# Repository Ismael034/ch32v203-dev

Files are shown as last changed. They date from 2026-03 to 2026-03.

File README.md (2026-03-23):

# ch32v203-devboard

Just another CH32V203 development board.

With dual USB, exposed GPIOs, and a SWD header, this board is meant to make it easy to create projects for the CH32V203 microcontroller.

## Screenshots

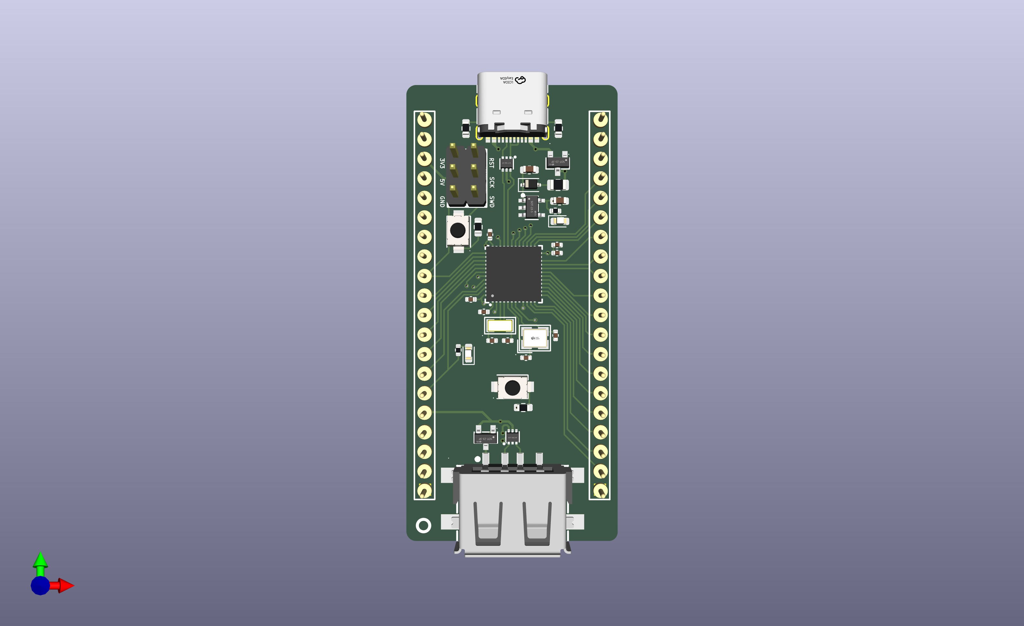
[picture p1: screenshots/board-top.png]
Board top

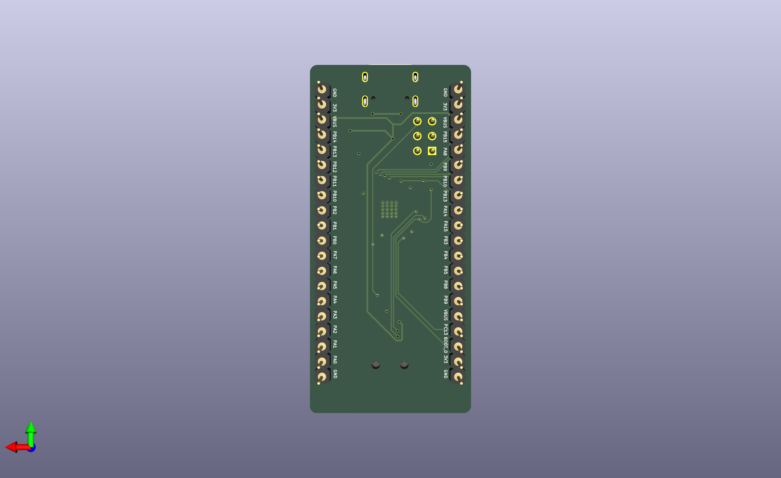
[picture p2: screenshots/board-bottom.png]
Board bottom

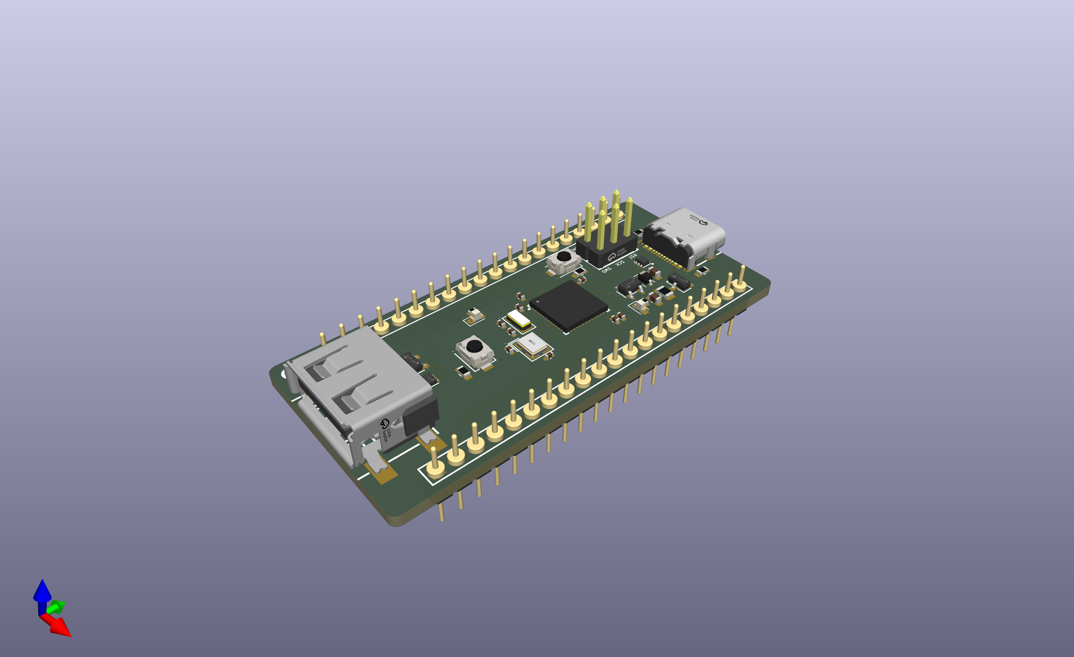
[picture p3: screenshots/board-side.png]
Board side


## BOM

| Qty | Designators | Description | Footprint |
| --- | --- | --- | --- |
| 2 | C1, C2 | 10 uF capacitors | `Capacitor_SMD:C_0603_1608Metric` |
| 4 | C3, C4, C9, C10 | 15 pF capacitors | `Capacitor_SMD:C_0402_1005Metric` |
| 3 | C5, C6, C7 | 100 nF capacitors | `Capacitor_SMD:C_0402_1005Metric` |
| 1 | C8 | 4.7 uF capacitor | `Capacitor_SMD:C_0402_1005Metric` |
| 1 | C11 | 10 uF capacitor | `Capacitor_SMD:C_0402_1005Metric` |
| 2 | D1, D2 | USBLC6-2P6 ESD protection | `ch32v203_dev:SOT-666-6_L1.6-W1.2-P0.50-LS1.6-BL` |
| 1 | F1 | JK-SMD0805-020-30V fuse | `Fuse:Fuse_0805_2012Metric` |
| 2 | H1, H2 | 1x20 2.54 mm pin headers | `ch32v203_dev:HDR-TH_20P-P2.54-V-M_4` |
| 1 | LED1 | User LED, XL-1608UGC-04 | `LED_SMD:LED_0603_1608Metric` |
| 1 | LDO1 | ME6211C33M5G-N 3.3 V LDO | `ch32v203_dev:SOT-23-5_L3.0-W1.7-P0.95-LS2.8-BL` |
| 1 | PWR1 | Power LED, NCD0603R1 | `LED_SMD:LED_0603_1608Metric` |
| 2 | R2, R3 | 10 kOhm resistors | `Resistor_SMD:R_0603_1608Metric` |
| 2 | R4, R5 | 1 kOhm resistors | `Resistor_SMD:R_0402_1005Metric` |
| 2 | R1, R6 | 5.1 kOhm resistors | `Resistor_SMD:R_0603_1608Metric` |
| 2 | RESET1, RESET2 | SMD tactile switches | `ch32v203_dev:SW-SMD_L3.9-W3.0-P4.45` |
| 1 | U1 | CH32V203C8U6 MCU | `ch32v203_dev:TQFN-48_L7.0-W7.0-P0.50-BL-EP5.5` |
| 1 | U2 | 2x3 2.54 mm SWD header | `ch32v203_dev:HDR-TH_6P-P2.54-V-M-R3-C2-S2.54_2` |
| 1 | U3 | 32.768 kHz crystal | `ch32v203_dev:CRYSTAL-SMD_L3.2-W1.5-1` |
| 1 | U4 | USB-C receptacle KH-TYPE-C-16P | `ch32v203_dev:USB-C-SMD_KH-TYPE-C-16P` |
| 1 | U5 | SD101CWS diode | `Diode_SMD:D_SOD-323` |
| 2 | U6, U7 | DMG2305UX-7 MOSFET | `ch32v203_dev:SOT-23-3_L2.9-W1.3-P1.90-LS2.4-BR` |
| 1 | USB2 | USB-A receptacle 10.0 QTJ6.3 | `ch32v203_dev:USB-A-SMD_10.0-QTJ6.3` |
| 1 | X1 | 8 MHz crystal | `ch32v203_dev:CRYSTAL-SMD_4P-L3.2-W2.5-BL` |

## Some notes

- You can either program the board using the USB-C port (by pressing the BOOT button while plugging in the USB cable) or using the SWD header.
- The board has a built-in LED mapped to PB9.
- The board dimensions are 27.9mm (takes 10 breadboard pins) x 59.9mm

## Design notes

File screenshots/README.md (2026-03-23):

# Screenshots

Drop rendered images or board photos here.

Suggested files:

- `board-top.png`
- `board-bottom.png`
- `schematic-overview.png`
- `3d-view.png`

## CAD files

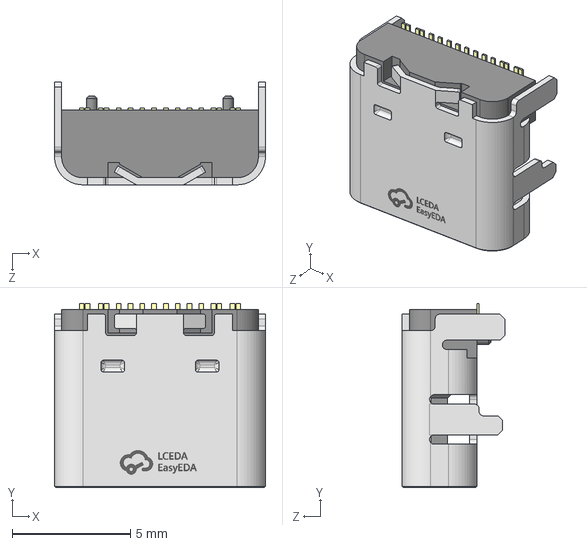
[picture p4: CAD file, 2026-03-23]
ch32v203_dev_fp/ch32v203_dev_model/USB-C-SMD_KH-TYPE-C-16P.step
8.94 x 7.81 x 4.35 mm

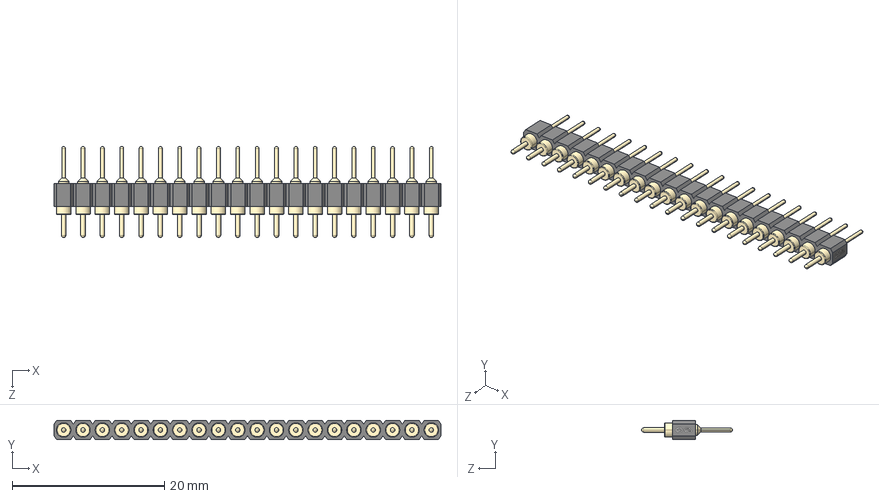
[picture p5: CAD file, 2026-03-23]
ch32v203_dev_fp/ch32v203_dev_model/HDR-TH_20P-P2.54-V-M_4.step
50.8 x 2.54 x 12.0 mm

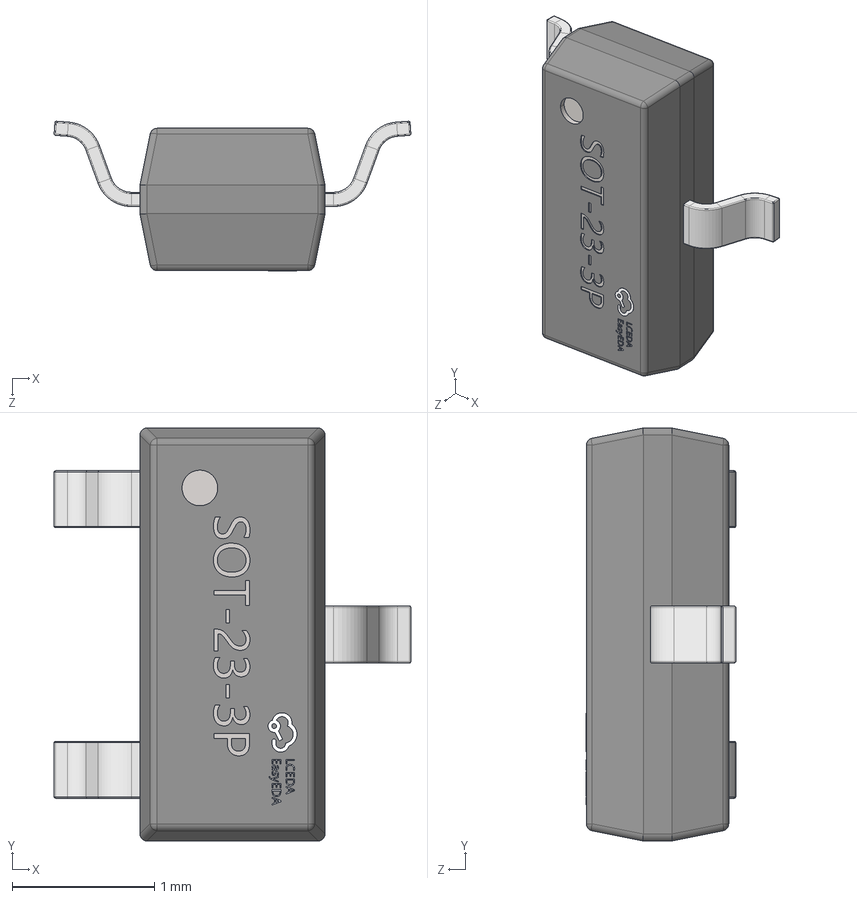
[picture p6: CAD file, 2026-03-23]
ch32v203_dev_fp/ch32v203_dev_model/SOT-23-3_L2.9-W1.3-P1.90-LS2.4-BR.step
2.51 x 2.90 x 1.05 mm

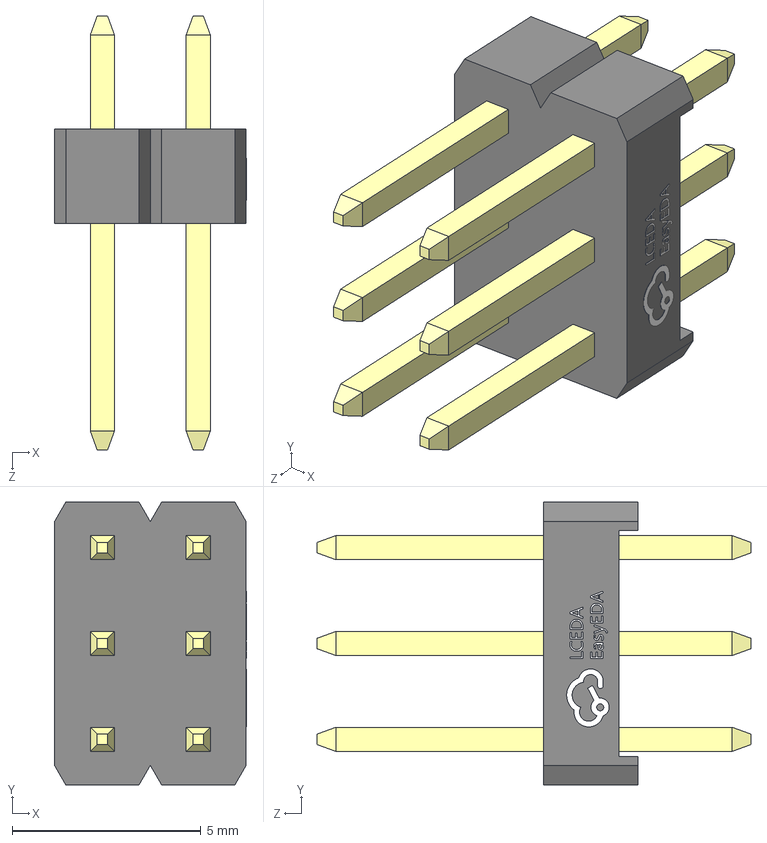
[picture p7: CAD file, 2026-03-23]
ch32v203_dev_fp/ch32v203_dev_model/HDR-TH_6P-P2.54-V-M-R3-C2-S2.54_2.step
5.09 x 7.50 x 11.5 mm

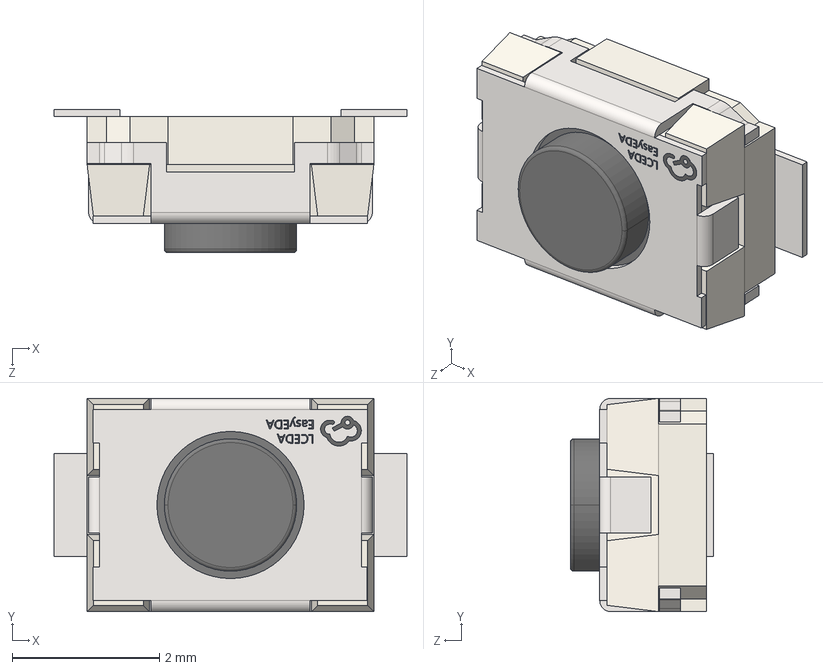
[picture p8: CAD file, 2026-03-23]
ch32v203_dev_fp/ch32v203_dev_model/SW-SMD_L3.9-W3.0-P4.45.step
4.80 x 2.90 x 1.95 mm

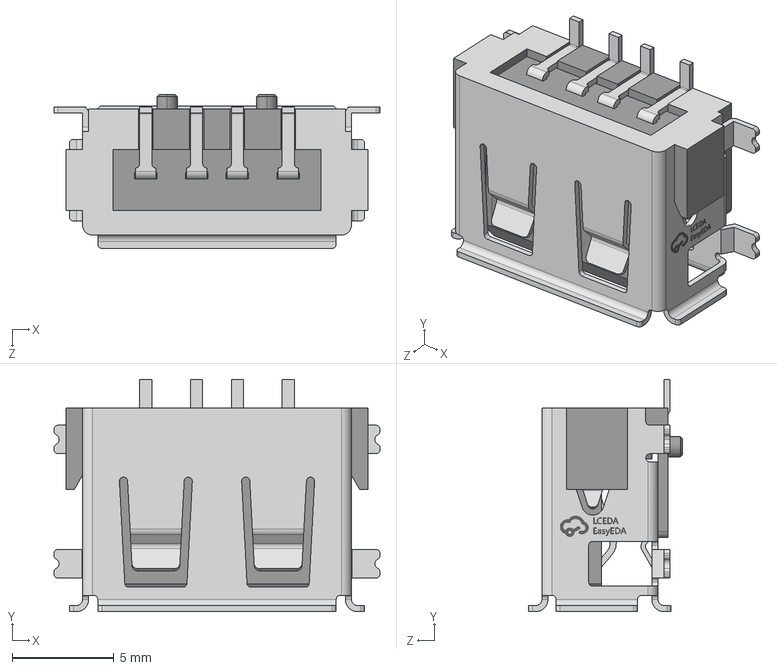
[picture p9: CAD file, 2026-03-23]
ch32v203_dev_fp/ch32v203_dev_model/USB-A-SMD_10.0-QTJ6.3.step
16.0 x 11.4 x 7.55 mm

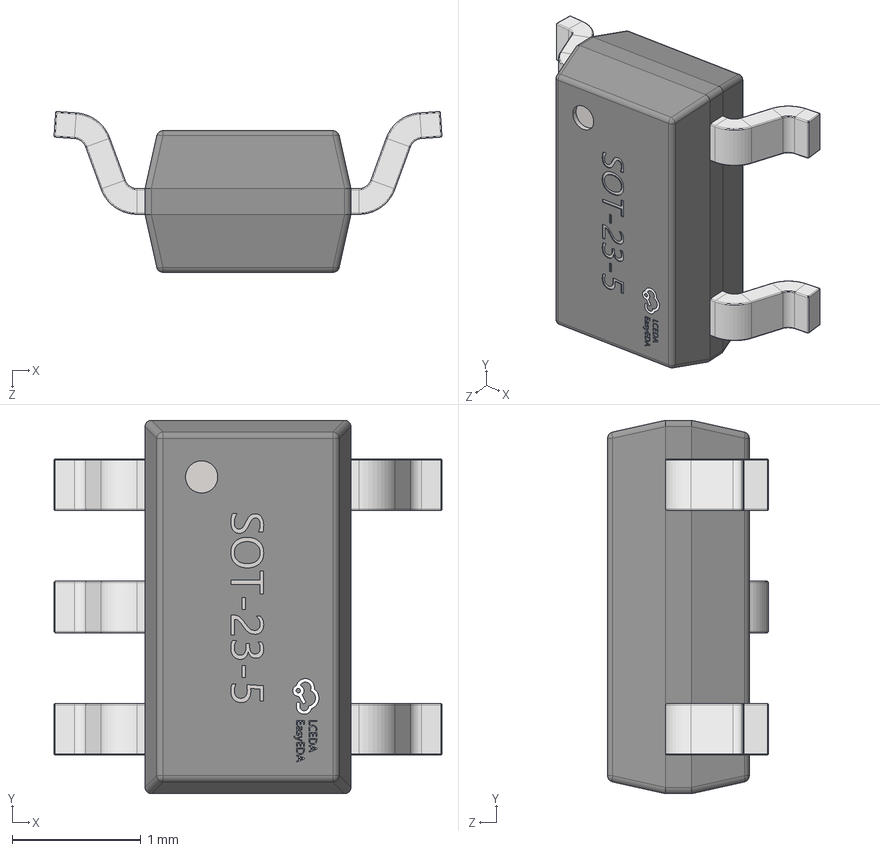
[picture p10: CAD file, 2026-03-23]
ch32v203_dev_fp/ch32v203_dev_model/SOT-23-5_L3.0-W1.7-P0.95-LS2.8-BL.step
3.01 x 2.90 x 1.25 mm

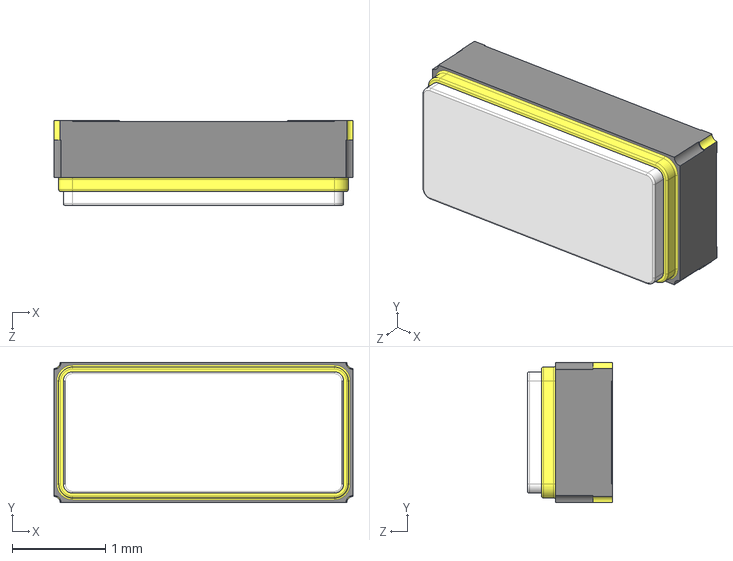
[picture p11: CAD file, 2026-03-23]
ch32v203_dev_fp/ch32v203_dev_model/CRYSTAL-SMD_L3.2-W1.5-1.step
3.20 x 1.50 x 0.91 mm

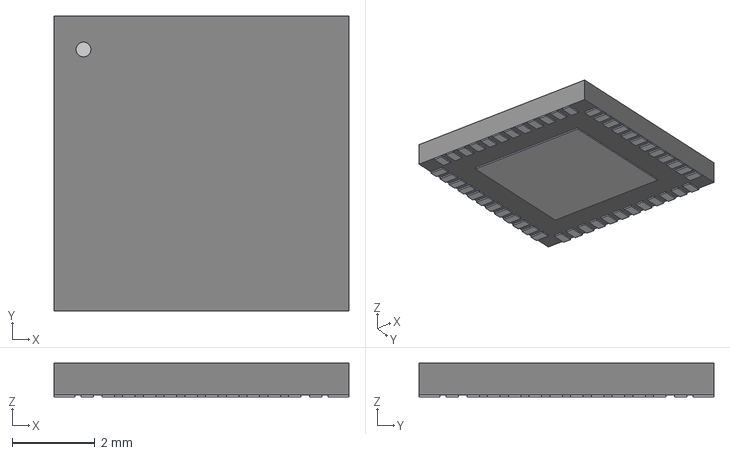
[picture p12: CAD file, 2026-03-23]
ch32v203_dev_fp/ch32v203_dev_model/TQFN-48_L7.0-W7.0-P0.50-BL-EP5.5.step
7.11 x 7.11 x 0.815 mm

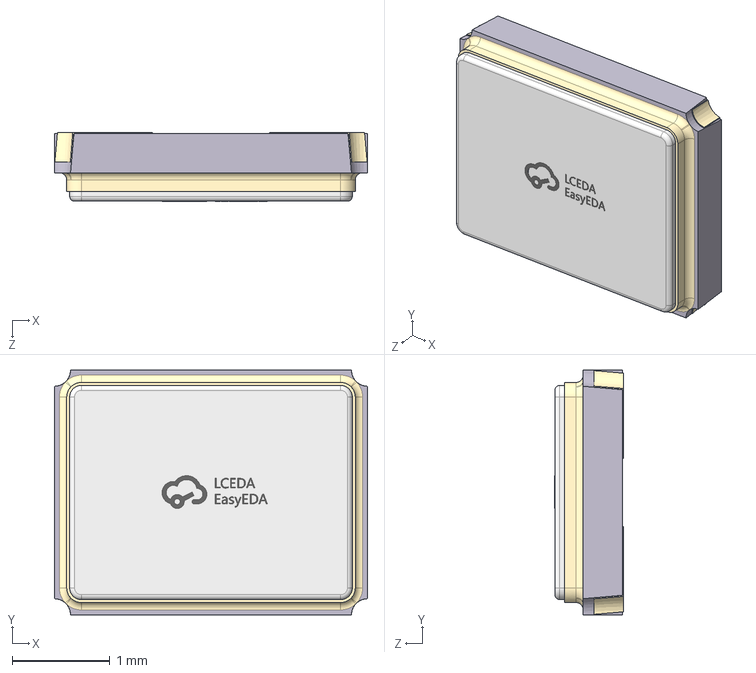
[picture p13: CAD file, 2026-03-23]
ch32v203_dev_fp/ch32v203_dev_model/CRYSTAL-SMD_4P-L3.2-W2.5-BL.step
3.20 x 2.50 x 0.701 mm

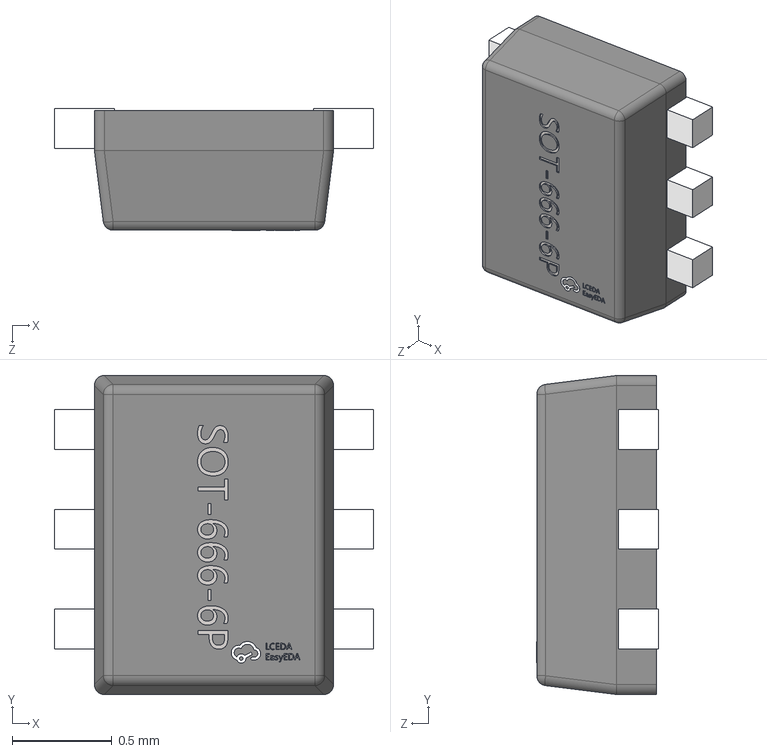
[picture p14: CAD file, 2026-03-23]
ch32v203_dev_fp/ch32v203_dev_model/SOT-666-6_L1.6-W1.2-P0.50-LS1.6-BL.step
1.60 x 1.60 x 0.611 mm

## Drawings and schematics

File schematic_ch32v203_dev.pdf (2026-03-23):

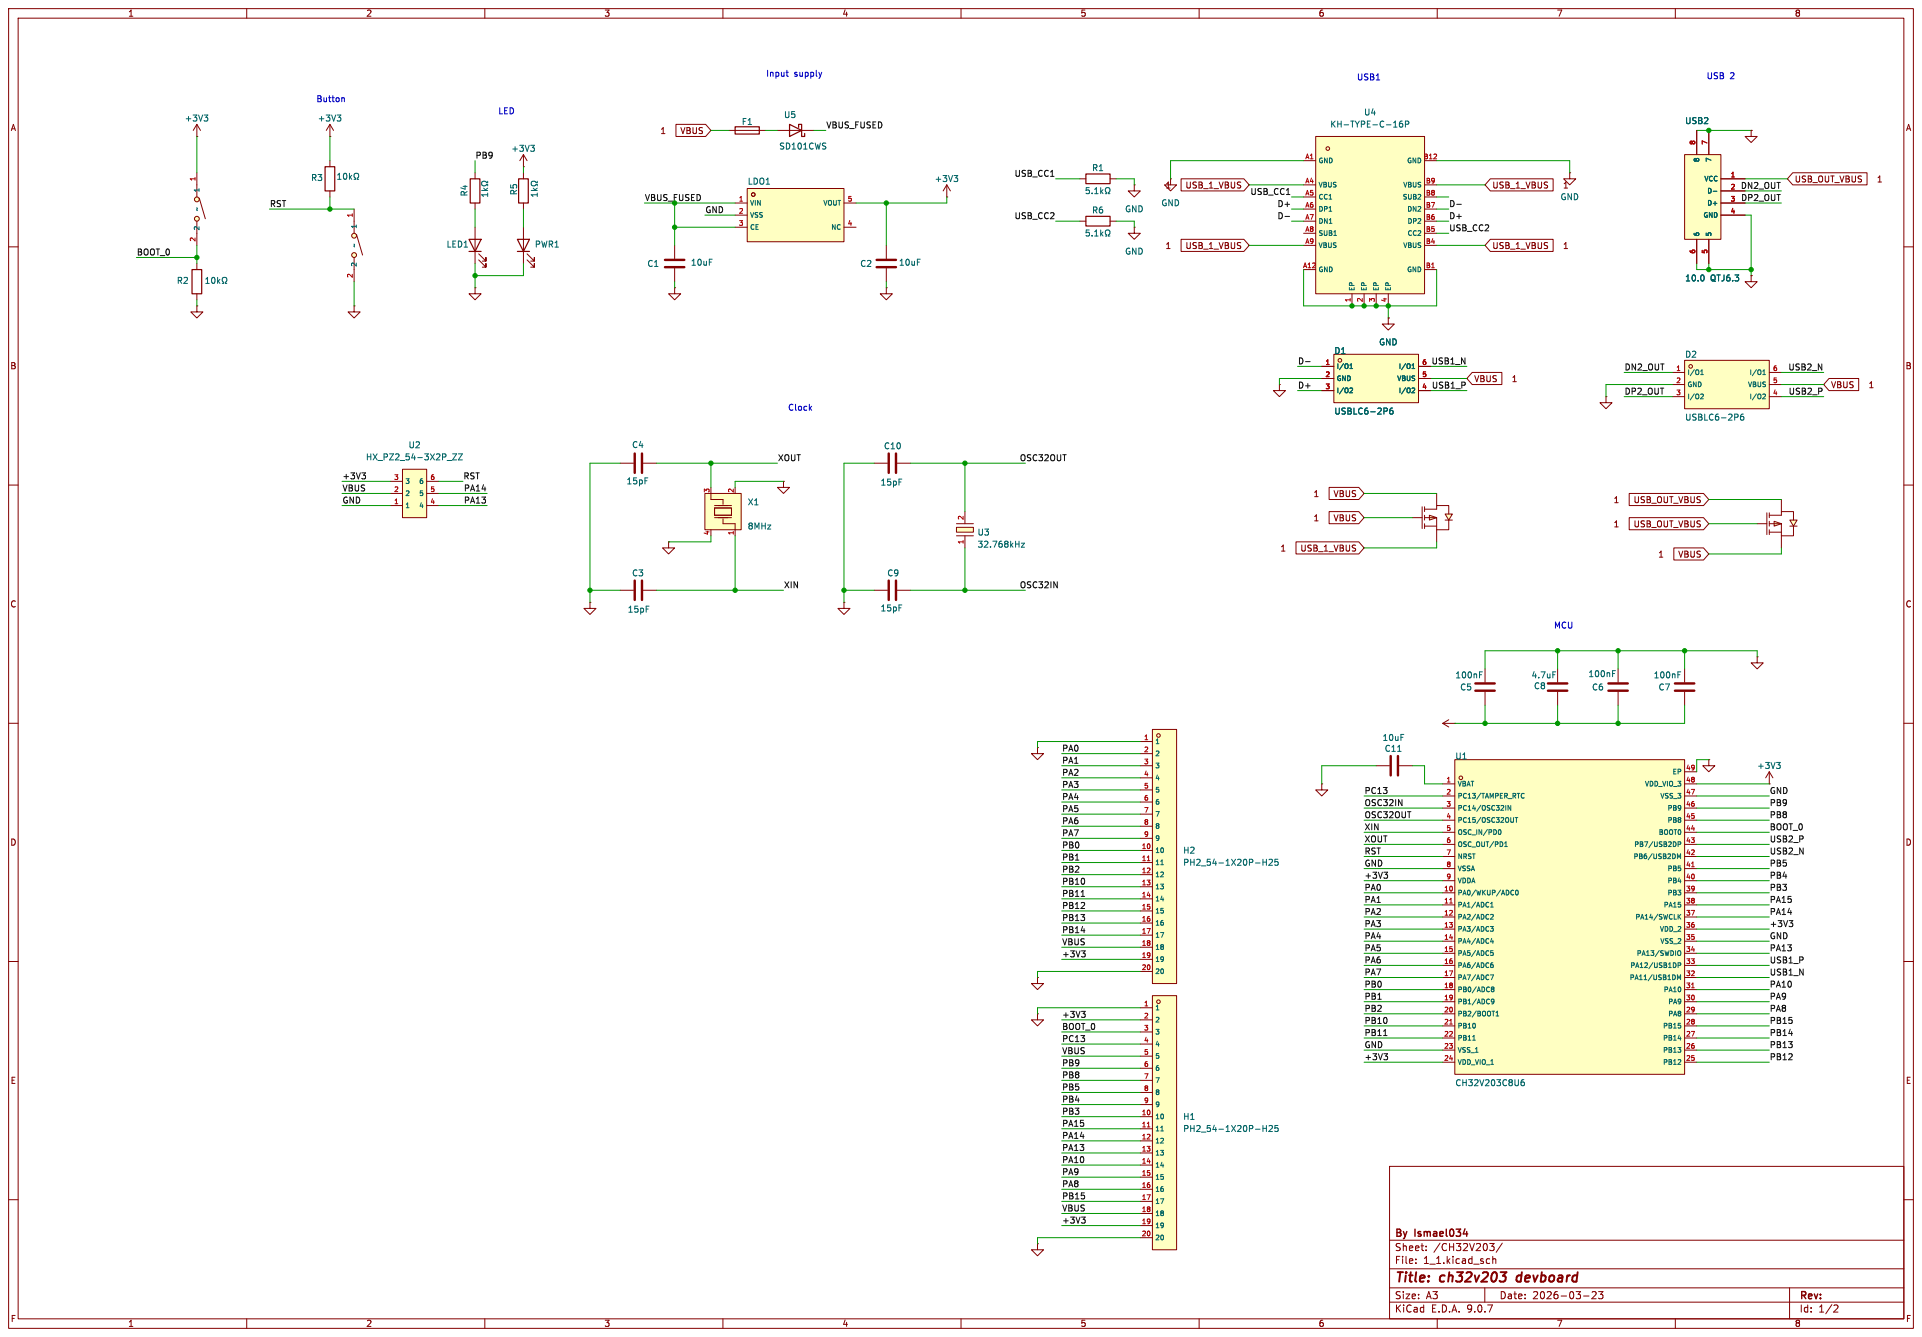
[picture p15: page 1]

4 GND B12 VBUS B9 SUB2 B8 DN2 B7 DP2 B6 CC2 B5 VBUS B4 GND B1 U4 KH-TYPE-C-16P GND

XIN OSC32OUT RST XOUT PA1 PA0 +3V3 PA2 GND

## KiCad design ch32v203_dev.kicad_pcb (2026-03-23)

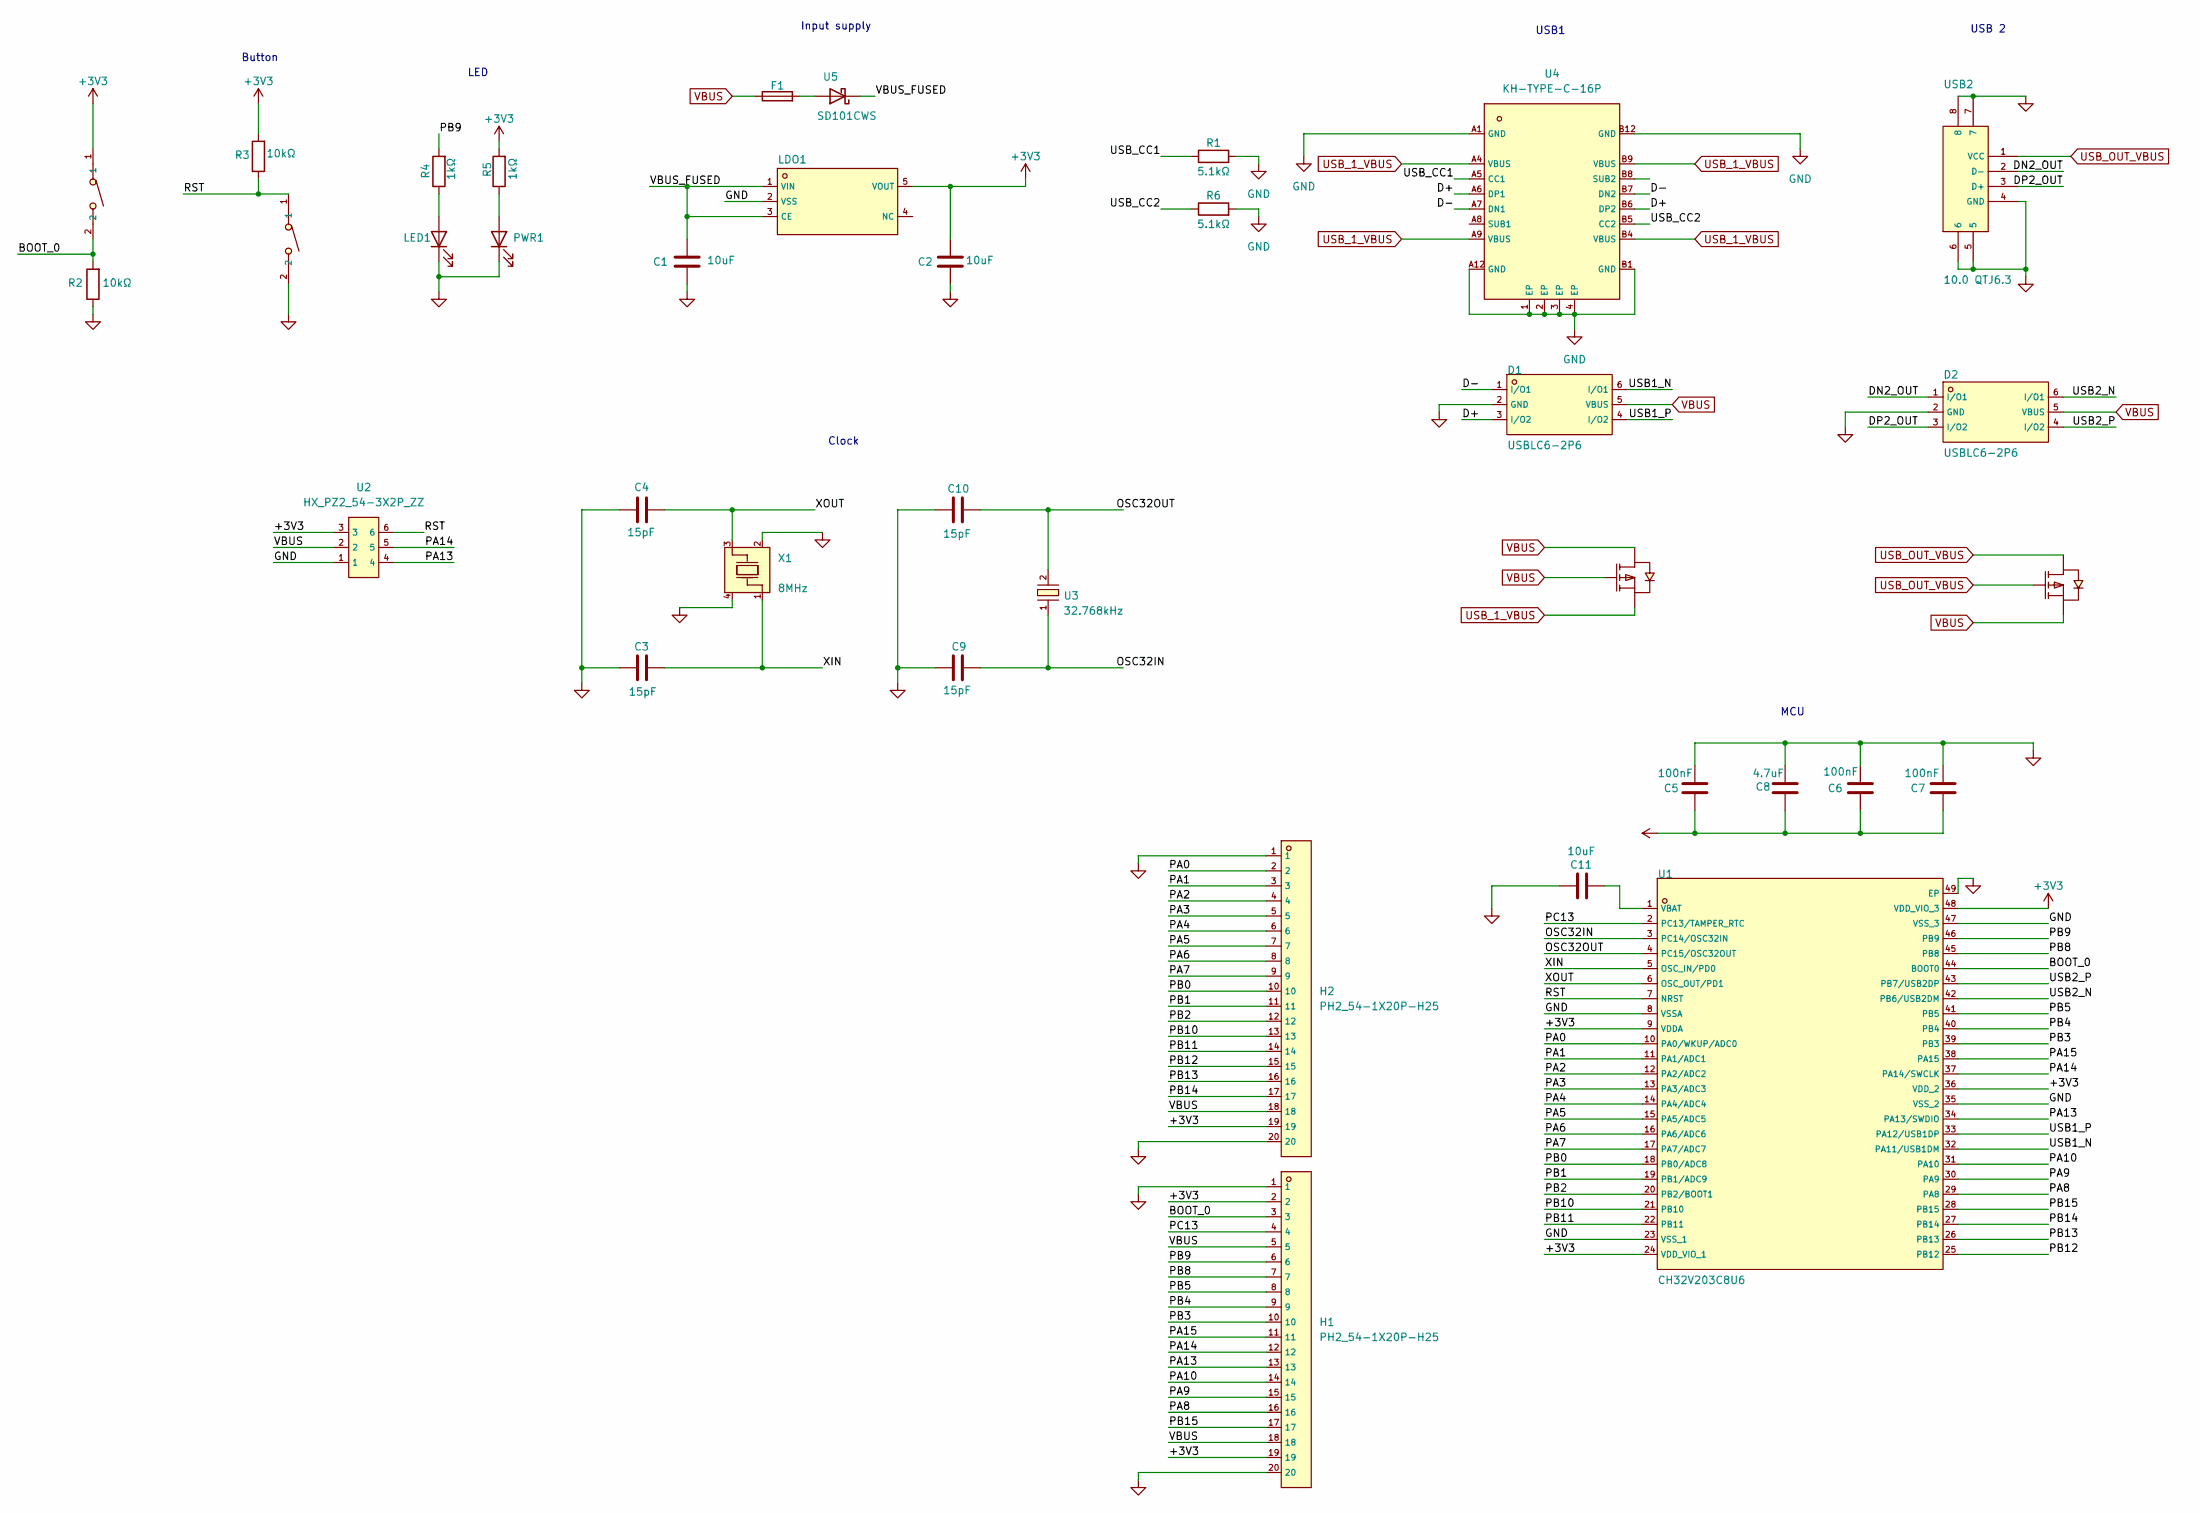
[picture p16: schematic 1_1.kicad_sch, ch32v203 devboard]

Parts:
C1, C2: 10uF; C_0603_1608Metric; Voltage Rating 10V; Manufacturer Part CGA0603X5R106K100JT; LCSC Part Name 10uF ±10% 10V
C3, C4, C9, C10: 15pF; C_0402_1005Metric; Manufacturer Part 0402CG150J500NT; LCSC Part Name 15pF ±5% 50V
C5, C6, C7: 100nF; C_0402_1005Metric; Manufacturer Part CGA0603X7R104K500JT; LCSC Part Name 100nF ±10% 50V
C8: 4.7uF; C_0402_1005Metric; Manufacturer Part CL10A475KP8NNNC; LCSC Part Name 4.7uF ±10% 10V
C11: 10uF; C_0402_1005Metric; Voltage Rating 10V; Manufacturer Part CGA0603X5R106K100JT; LCSC Part Name 10uF ±10% 10V
D1, D2: USBLC6-2P6; SOT-666-6_L1.6-W1.2-P0.50-LS1.6-BL; Manufacturer Part USBLC6-2P6; LCSC Part Name MSL=3
F1: JK-SMD0805-020-30V; Fuse_0805_2012Metric; Manufacturer Part JK-SMD0805-020-30V; LCSC Part Name 30V 200mA 0805自恢复
H1, H2: PH2_54-1X20P-H25; HDR-TH_20P-P2.54-V-M_4; LCSC C42431804
LDO1: ME6211C33M5G-N; SOT-23-5_L3.0-W1.7-P0.95-LS2.8-BL; Manufacturer Part ME6211C33M5G-N; LCSC Part Name 输入6V 输出3.3V 500mA
LED1: XL-1608UGC-04; LED_0603_1608Metric; Manufacturer Part XL-1608UGC-04; LCSC Part Name XL-1608UGC-04
PWR1: NCD0603R1; LED_0603_1608Metric; Manufacturer Part NCD0603R1; LCSC Part Name NCD0603R1
R1, R6: 5.1kΩ; R_0603_1608Metric
R2, R3: 10kΩ; R_0603_1608Metric; Manufacturer Part RC0603JR-0710KL; LCSC Part Name 厚膜电阻 10kΩ ±5% 100mW
R4, R5: 1kΩ; R_0402_1005Metric; Manufacturer Part 0402WGF1001TCE; LCSC Part Name 1kΩ ±1% 62.5mW 厚膜电阻
RESET1, RESET2: SW-SMD_L3.9-W3.0-P4.45; Manufacturer Part TS-1088-AR02016; LCSC Part Name 4*3*2mm 立贴 轻触开关
U1: CH32V203C8U6; TQFN-48_L7.0-W7.0-P0.50-BL-EP5.5; Manufacturer Part CH32V203C8U6; LCSC Part Name CH32V203C8U6
U2: HX_PZ2_54-3X2P_ZZ; HDR-TH_6P-P2.54-V-M-R3-C2-S2.54_2; LCSC C32713289
U3: 32.768kHz; CRYSTAL-SMD_L3.2-W1.5-1; Manufacturer Part H31003271C2070CY; LCSC Part Name 32.768kHz ±20ppm 12.5pF
U4: KH-TYPE-C-16P; USB-C-SMD_KH-TYPE-C-16P; LCSC C709357
U5: SD101CWS; D_SOD-323; Manufacturer Part SD101CWS; LCSC Part Name SD101CWS
U6, U7: DMG2305UX-7; SOT-23-3_L2.9-W1.3-P1.90-LS2.4-BR; LCSC C150470
USB2: 10.0 QTJ6.3; USB-A-SMD_10.0-QTJ6.3; Manufacturer Part 10.0 QTJ6.3; LCSC Part Name Type-A 母 卧贴
X1: 8MHz; CRYSTAL-SMD_4P-L3.2-W2.5-BL; Manufacturer Part TAXM8M4RDBCCT2T; LCSC Part Name 8MHz ±10ppm 10pF

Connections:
+3V3: C2.2, C5.1, C6.1, C7.1, C8.1, H1.2, H1.19, H2.19, LDO1.5 (VOUT), R3.2, R5.2, RESET2.1, U1.9 (VDDA), U1.24 (VDD_VIO_1), U1.36 (VDD_2), U1.48 (VDD_VIO_3), U2.3
/CH32V203/BOOT_0: H1.3, R2.2, RESET2.2, U1.44 (BOOT0)
/CH32V203/D+: D1.3 (I/O2), U4.A6 (DP1), U4.B6 (DP2)
/CH32V203/D-: D1.1 (I/O1), U4.A7 (DN1), U4.B7 (DN2)
/CH32V203/DN2_OUT: D2.1 (I/O1), USB2.2 (D-)
/CH32V203/DP2_OUT: D2.3 (I/O2), USB2.3 (D+)
/CH32V203/OSC32IN: C9.2, U1.3 (PC14/OSC32IN), U3.1
/CH32V203/OSC32OUT: C10.1, U1.4 (PC15/OSC32OUT), U3.2
/CH32V203/PA0: H2.2, U1.10 (PA0/WKUP/ADC0)
/CH32V203/PA1: H2.3, U1.11 (PA1/ADC1)
/CH32V203/PA2: H2.4, U1.12 (PA2/ADC2)
/CH32V203/PA3: H2.5, U1.13 (PA3/ADC3)
/CH32V203/PA4: H2.6, U1.14 (PA4/ADC4)
/CH32V203/PA5: H2.7, U1.15 (PA5/ADC5)
/CH32V203/PA6: H2.8, U1.16 (PA6/ADC6)
/CH32V203/PA7: H2.9, U1.17 (PA7/ADC7)
/CH32V203/PA8: H1.16, U1.29 (PA8)
/CH32V203/PA9: H1.15, U1.30 (PA9)
/CH32V203/PA10: H1.14, U1.31 (PA10)
/CH32V203/PA13: H1.13, U1.34 (PA13/SWDIO), U2.4
/CH32V203/PA14: H1.12, U1.37 (PA14/SWCLK), U2.5
/CH32V203/PA15: H1.11, U1.38 (PA15)
/CH32V203/PB0: H2.10, U1.18 (PB0/ADC8)
/CH32V203/PB1: H2.11, U1.19 (PB1/ADC9)
/CH32V203/PB2: H2.12, U1.20 (PB2/BOOT1)
/CH32V203/PB3: H1.10, U1.39 (PB3)
/CH32V203/PB4: H1.9, U1.40 (PB4)
/CH32V203/PB5: H1.8, U1.41 (PB5)
/CH32V203/PB8: H1.7, U1.45 (PB8)
/CH32V203/PB9: H1.6, R4.2, U1.46 (PB9)
/CH32V203/PB10: H2.13, U1.21 (PB10)
/CH32V203/PB11: H2.14, U1.22 (PB11)
/CH32V203/PB12: H2.15, U1.25 (PB12)
/CH32V203/PB13: H2.16, U1.26 (PB13)
/CH32V203/PB14: H2.17, U1.27 (PB14)
/CH32V203/PB15: H1.17, U1.28 (PB15)
/CH32V203/PC13: H1.4, U1.2 (PC13/TAMPER_RTC)
/CH32V203/RST: R3.1, RESET1.1, U1.7 (NRST), U2.6
/CH32V203/USB1_N: D1.6 (I/O1), U1.32 (PA11/USB1DM)
/CH32V203/USB1_P: D1.4 (I/O2), U1.33 (PA12/USB1DP)
/CH32V203/USB2_N: D2.6 (I/O1), U1.42 (PB6/USB2DM)
/CH32V203/USB2_P: D2.4 (I/O2), U1.43 (PB7/USB2DP)
/CH32V203/USB_CC1: R1.1, U4.A5 (CC1)
/CH32V203/USB_CC2: R6.1, U4.B5 (CC2)
/CH32V203/VBUS_FUSED: C1.2, LDO1.1 (VIN), LDO1.3 (CE), U5.1 (K)
/CH32V203/XIN: C3.2, U1.5 (OSC_IN/PD0), X1.1
/CH32V203/XOUT: C4.1, U1.6 (OSC_OUT/PD1), X1.3
GND: C1.1, C2.1, C3.1, C4.2, C5.2, C6.2, C7.2, C8.2, C9.1, C10.2, C11.2, D1.2 (GND), D2.2 (GND), H1.1, H1.20, H2.1, H2.20, LDO1.2 (VSS), LED1.1 (K), PWR1.1 (K), R1.2, R2.1, R6.2, RESET1.2, U1.8 (VSSA), U1.23 (VSS_1), U1.35 (VSS_2), U1.47 (VSS_3), U1.49 (EP), U2.1, U4.1 (EP), U4.2 (EP), U4.3 (EP), U4.4 (EP), U4.A1 (GND), U4.A12 (GND), U4.B1 (GND), U4.B12 (GND), USB2.4 (GND), USB2.5, USB2.6, USB2.7, USB2.8, X1.2, X1.4
unnamed: LED1.2 (A), R4.1
unnamed: PWR1.2 (A), R5.1
unnamed: C11.1, U1.1 (VBAT)
unnamed: F1.2, U5.2 (A)
USB_1_VBUS: U4.A4 (VBUS), U4.A9 (VBUS), U4.B4 (VBUS), U4.B9 (VBUS), U6.2 (S)
USB_OUT_VBUS: U7.1 (G), U7.3 (D), USB2.1 (VCC)
VBUS: D1.5 (VBUS), D2.5 (VBUS), F1.1, H1.5, H1.18, H2.18, U2.2, U6.1 (G), U6.3 (D), U7.2 (S)

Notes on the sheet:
Clock
Button
USB1
Input supply
USB 2
LED
MCU

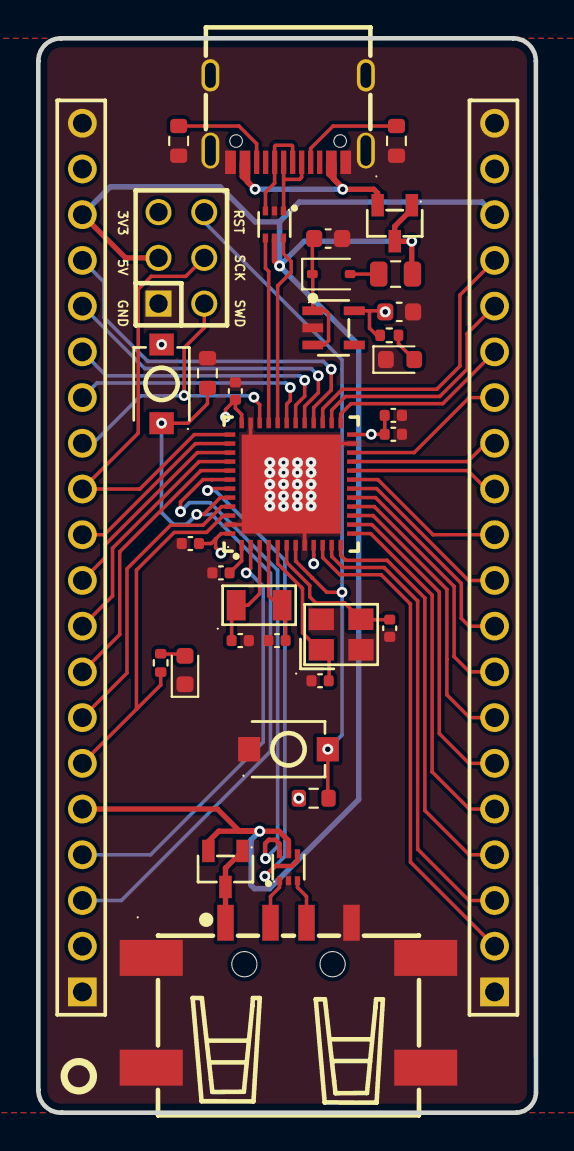
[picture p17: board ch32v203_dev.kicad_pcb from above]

Board: 4 copper layers, 27.7 x 59.7 mm, 36 parts (0 on the bottom side), 55 nets.

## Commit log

2026-03-23 doc: add bom
2026-03-23 chore: reset components anotation
    [1_1.kicad_sch, ch32v203_dev.kicad_pcb]
2026-03-23 chore: update schematics pdf
